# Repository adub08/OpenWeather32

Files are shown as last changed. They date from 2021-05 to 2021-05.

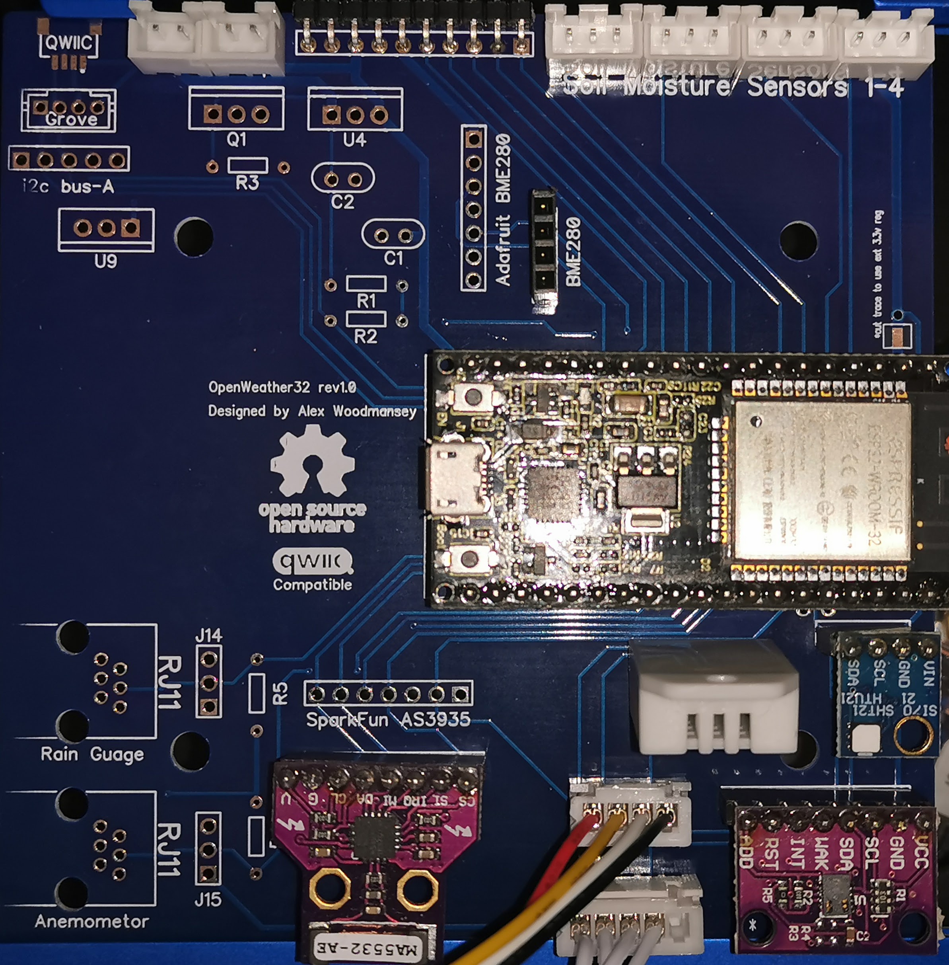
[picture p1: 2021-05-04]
renders & photos/Populated Board.jpg

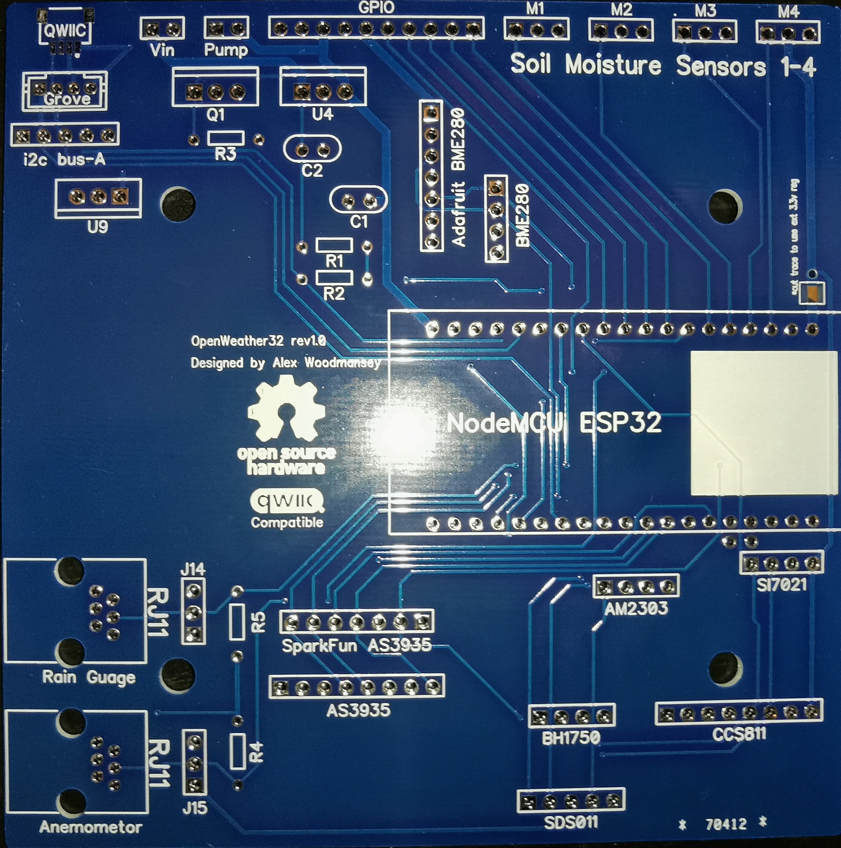
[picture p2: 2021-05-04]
renders & photos/Board.jpg

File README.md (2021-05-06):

# OpenWeather32
Open Source ESP32 based weather and air quality station, designed around sensors supported by ESPHome

 
# What?
OpenWeather32 is designed to be a flexible DIY friendly weather and air quality monitoring system (with many additional features!)

# Features: 
- DIY friendly thru-hole design with most pins labelled 
- Based around a NodeMCU ESP32 & designed to work with ESPHome
- Battery monitoring using Vin voltage divider 
- 5V OR 6.5 - 32V DC input (when populated with TSR12450)
- Optional dedicated Voltage regulator for QWIIC/Grove i2c bus for a high number of QWIIC devices
- QWIIC compatible (Dedicated i2c Bus-A)
- Grove compatible (Dedicated i2c Bus-A)
- Mosfet controlled pump or solenoid output
- RJ-11 (or 2.54 dupoint) Rain guage and anemometer inputs **[Untested]**
- 5 spare GPIO pins (5 support ADC functions, 2 support DAC, 3 support capacitive touch)

**Supported Sensors:**
- Supports a wide variety of temperature and humidity sensors including:
  - BME280 (Adafruit or other pin-outs)
  - AM2303 (otherwise known as the DHT22)
  - SI7021
- Support the CCS811 CO2 and VOC (volatile organic compound) sensor
- Supports the SDS011 particulate Matter Sensor
- Supports the BH1750 Ambient Light Sensor
- AMS AS3935 Franklin Lightning Sensor [Connected via SPI]
- Four capacitive soil moisture sensors 
- Any QWIIC or Grove compatible sensor board

**PCB Design Features**
- All 2.54 headers placed on a 2.54mm grid for easy soldering 
- Beginner friendly all thru hole soldering (minus the QWIIC connector)

# Why?
Although there are many other open source weather stations out there, not many are based around the ESP32 and most are just weather stations without any air quality or soil moisture sensing capabilities. There also seemed to be a huge lack of any designed around sensors supported by ESPHome I also wanted it to be flexible enough for most people's needs (which is why the variety of connector headers).

# How to use it?
I've exported the gerbers and odb++ files for the PCB layout, to make it just upload these files to your favourite PCB fab. I made the PCB 100x100mm, 2 layers, so that it would be suitable for being produced at dirtyPCB as a prototype run. If you wish to edit the PCB i suggest using diptrace, which is what i used to make this, the PCB is well within the limitations of the free version of DipTrace. I have also included an eagle .brd but i can't speak for the usability of this file since it's exported from DipTrace.

The esphome yaml config has been included but you will almost certainly need to change i2c addresses to match the individual sensor boards used along with wifi and device details.

# Render & Photos:
**Render of the Revision 1.1 board**
TOP - Render
Bottom - Render

**Photos of the Revision 1.0 board**
Board
Board

# How to help:
If you like to say thanks for the design, feel free to use my dirtypcb shares link when ordering.
https://dirtypcbs.com/store/designer/details/a_dub/6520/openweather32
In the future i may also sell single boards on Tindie. 

# Disclaimer:
**The Eagle file is an export from diptrace, i have no idea how good an export it is**I have not tested all features on this PCB yet, inparticular the wind and rain meters. I also have not tested the adafruit BME280 & The SparkFun AS3935 header. **Check Board layout and if headers are suitable before use. I Make no promises about anything being correct!**

**Enjoy!**

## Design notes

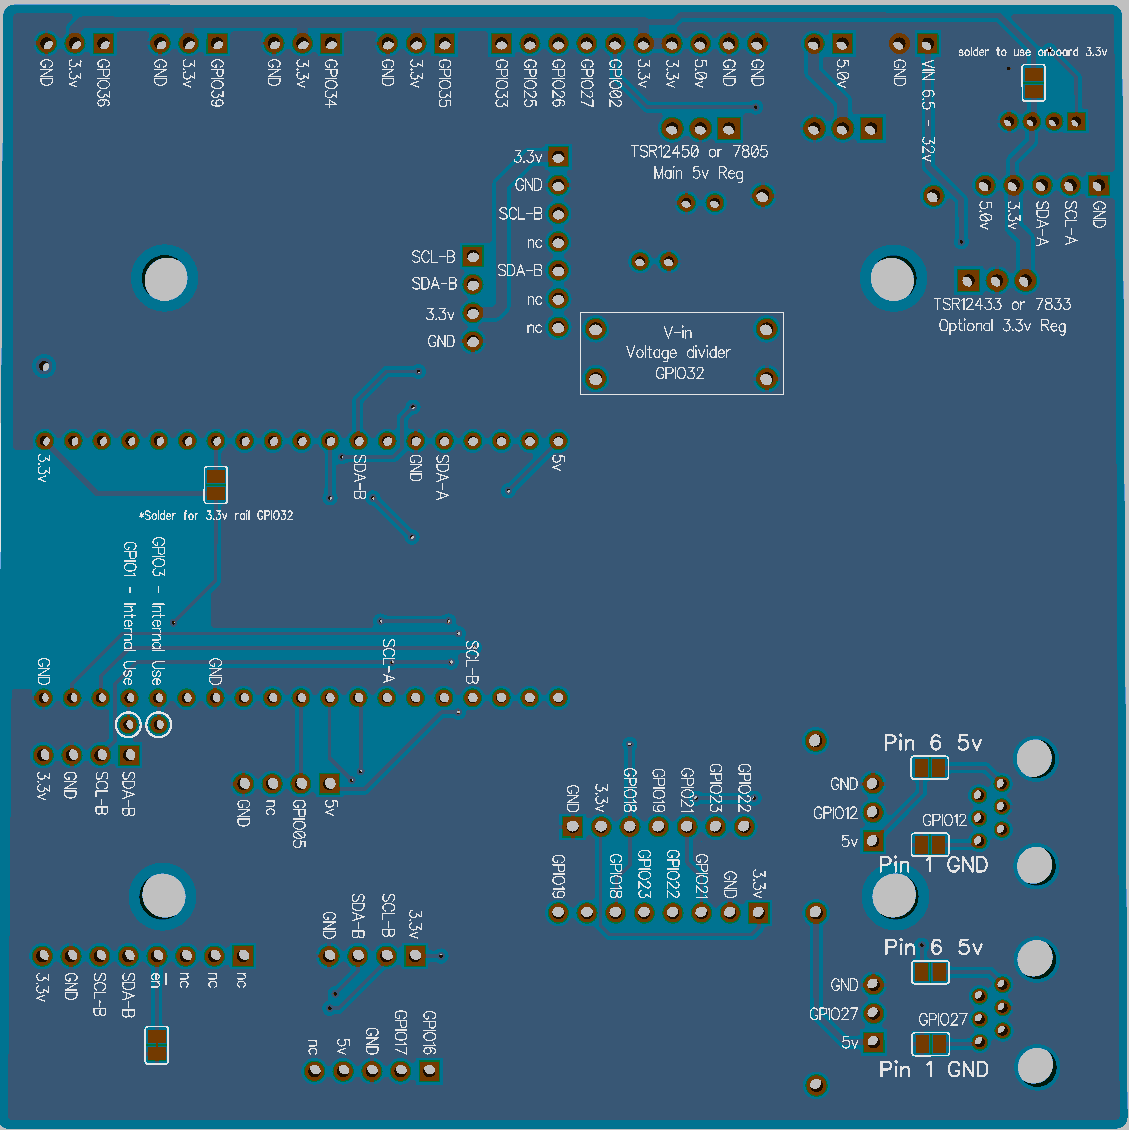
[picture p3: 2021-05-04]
renders & photos/Bottom - Render.PNG

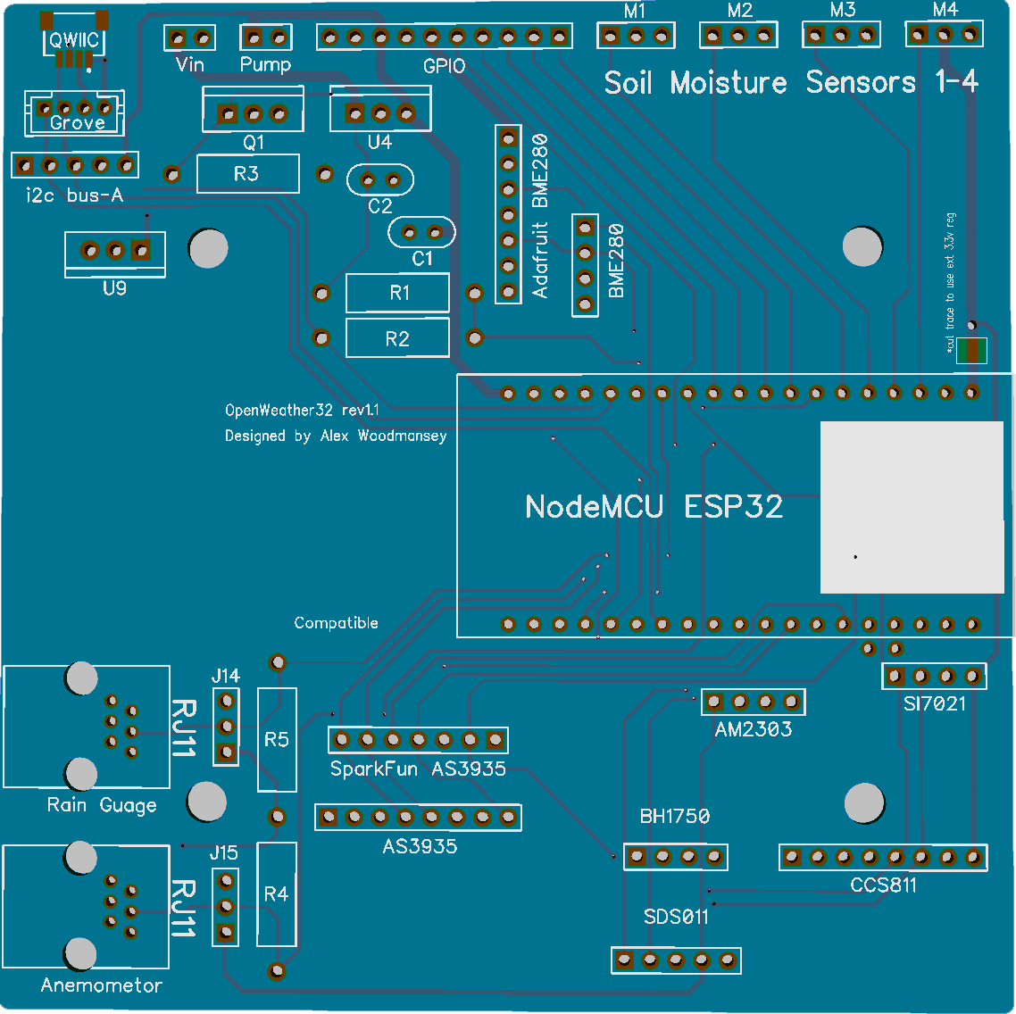
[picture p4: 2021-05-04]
renders & photos/TOP - Render.PNG

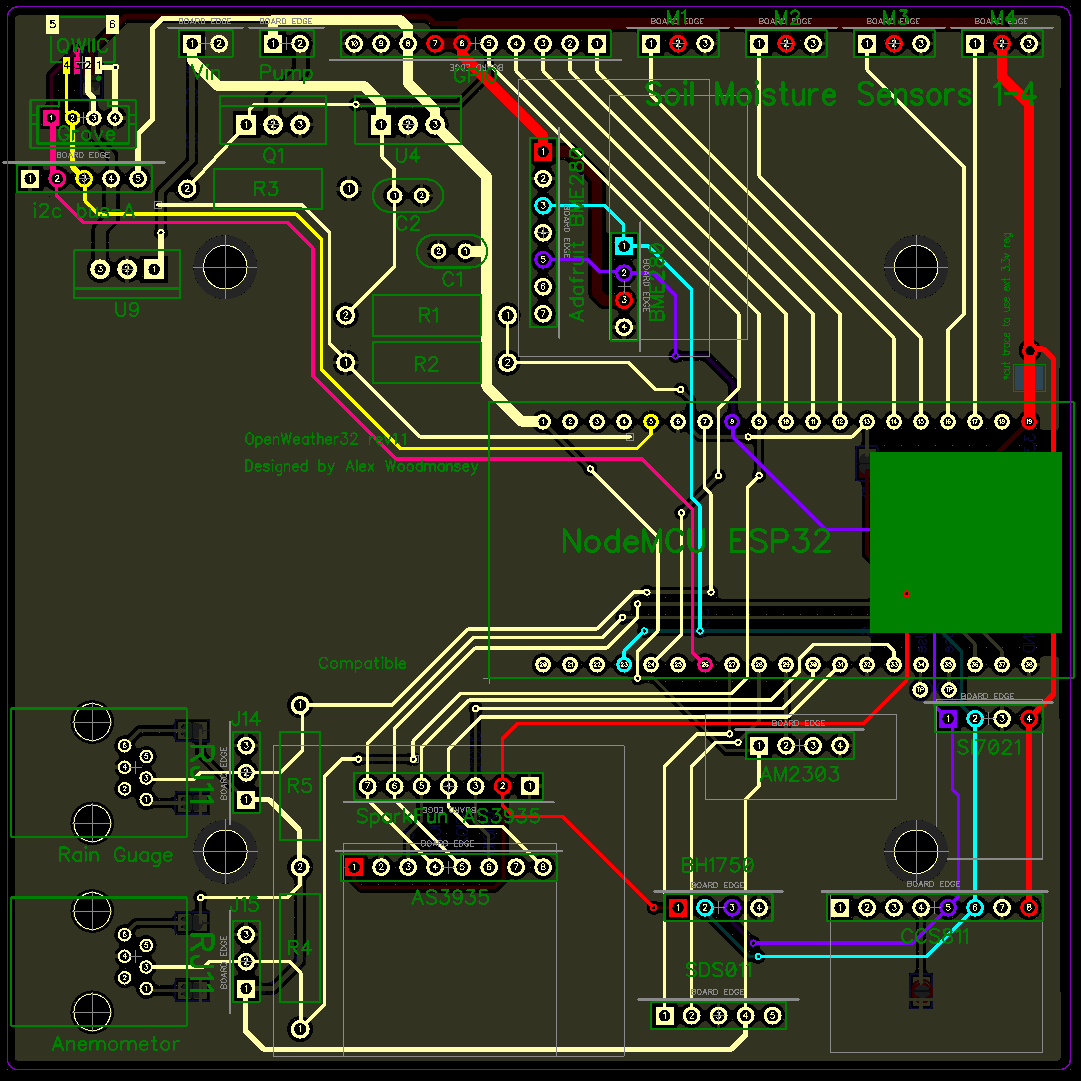
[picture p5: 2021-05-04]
renders & photos/layout.PNG

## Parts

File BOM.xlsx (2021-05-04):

Component | Description | Source #1 | Source #2 | Source #2
NodeMCU-32S |  | https://www.aliexpress.com/item/4000089201026.html | https://www.altronics.com.au/p/z6385a-esp-32s-wifi-bluetooth-module-and-interface-board/
BME280 | Temperature & humidity sensor | https://www.aliexpress.com/item/32871258550.html | https://www.altronics.com.au/p/z6455-bme280-temperature-humidity-pressure-sensor/
AM2303 | Temperature & humidity sensor | https://www.aliexpress.com/item/632552670.html | https://www.adafruit.com/product/385
SI7021 | Temperature & humidity sensor | https://www.aliexpress.com/item/32695384846.html
CCS811 | CO2 and VOC sensor | https://www.aliexpress.com/item/32981262907.html
SDS011 | particulate Matter Sensor | https://www.aliexpress.com/item/32894938003.html
BH1750 | Ambient Light Sensor | https://www.aliexpress.com/item/32722878671.html
AMS AS3935 | Franklin Lightning Sensor | https://www.aliexpress.com/item/33014615105.html
TSR 12450 | 5v switching regulator | https://au.element14.com/tracopower/tsr-1-2450/converter-dc-dc-5v-1a-sip/dp/1696320
TSR 12433 | 3.3v switching regulator | https://au.element14.com/traco-power/tsr-1-2433e/dc-dc-converter-3-3v-1a/dp/3470633
capacitive soil moisture sensor |  | https://www.aliexpress.com/item/32892951369.html
Connectors
JST SM4B-SRSS-TB | 4pin SH 1.0mm - QWIIC | https://www.aliexpress.com/item/32884852901.html | https://au.element14.com/jst-japan-solderless-terminals/sm04b-srss-tb-lf-sn/connector-header-smt-r-a-1mm-4way/dp/1830839 | https://www.adafruit.com/product/4208
JST XH2.54 -2pin | 2pin XH 2.54mm - soil moisture sensors | https://www.aliexpress.com/item/32954418743.html | https://au.element14.com/jst-japan-solderless-terminals/b2b-xh-a-lf-sn/header-vertical-2way/dp/1516276
JST XH2.54 -4pin | 4pin XH 2.54mm - BH1750 | https://www.aliexpress.com/item/32954418743.html | https://au.element14.com/jst-japan-solderless-terminals/b4b-xh-a-lf-sn/header-vertical-4way/dp/1516278
JST XH2.54 -5pin | 2pin XH 2.54mm - soil moisture sensors | https://www.aliexpress.com/item/32954418743.html | https://au.element14.com/jst-japan-solderless-terminals/s5b-xh-a/header-xh-side-5way-2-5mm/dp/1830882
B4B-PH-K-S - 4pin | 2pin PH 2.0mm - Grove | https://www.aliexpress.com/item/10000000870215.html | https://au.element14.com/jst-japan-solderless-terminals/b4b-ph-k-s-lf-sn/header-top-entry-4way-2mm/dp/9492437
Last updated: | 2021-05-04
This is not a complete list, it also may not be the cheapest sources or the best sources. Things Change!!! Do your own research!!!!
Please feel free to make this a more comprehensive list

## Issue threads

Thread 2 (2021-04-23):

XH JST connector labels silk screen are covered up once connectors are populated

adub08, 2021-04-23:

adub08, 2021-04-23:
Fixed with hardware revision 1.1

Closed 2021-04-23.

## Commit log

2021-03-31 Initial Commit
    Rev1.0 board design - Production revision.
2021-04-23 Revision 1.1
    Updated PCB layout to correct Issue #1 - Incorrect pinout for BME280
    header And Issues #2 - XH JST connector silk screen placement
    [BoardOutline.GBR, Bottom.GBL, BottomMask.GBS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]
2021-05-04 Revision 1.1
    Revision 1.1 updates.
    Added Eagle board export
    Added renders
    [PCB layout - Eagle.brd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]
2021-05-04 BOM uploads
    Added Bill of materials
    [BOM.xlsx]
